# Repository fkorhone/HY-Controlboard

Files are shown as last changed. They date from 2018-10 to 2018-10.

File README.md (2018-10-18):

# HY-Controlboard
General purpose microcontroller board for measurements and prototyping

## Copying
HY controlboard - Generic purpose control board for measurements and control
Copyright (c) 2018 Frans Korhonen

HY controlboard was originally developed at Institute for Atmospheric 
and Earth System Research / Physics, Faculty of Science, 
University of Helsinki, Finland

Assistance, experience, and feedback from following persons have been 
critical in the original work: Erkki Siivola, Lauri Ahonen, 
Juha Kangasluoma, Pasi Aalto, Markku Kulmala and Tuukka Petäjä.

This notice was encoded using utf-8.

This work is licensed under the Creative Commons Attribution-ShareAlike 4.0 International License. 

## Tools used
Drawings have been created using gEDA tools.
http://www.geda-project.org/

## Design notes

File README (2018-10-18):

2014 Frans Korhonen
README for easy geda bats.
Tools for designing printed circuit boards.

Run bats:
cmd.bat - command prompt with geda tools in path variables
X.bat - updates X.pcb from X.sch (Uses bat basename as filename). Follow the instructions on the appearing command window.
gattrib.bat - starts gattrib schematic attribute editor. Handy for setting component footprints and adding supplier references etc.
gerbv.bat - Gerber viewer. View production gerber layers.
gschem.bat - Schematic editor. Adds project related component symbols from "components/" directory.
pcb.bat - Layout editor. finds project related footprints from "packages/" directory. 
bom.bat - create bill of materials from schematics defined inside the bat.

directories:
components/ - project component symbol location.
packages - project fooprint location.
gerber/ - directory for pcb production gerbers.
src/ - firmware source code.
bom/ - Directory for bill of materials

other files:
gafrc - Required for project components seen properly.
round_mm_vendor - Vendor drill mapping file for PCB. mm drills.
attribs - fields that will be seen in bill of materials

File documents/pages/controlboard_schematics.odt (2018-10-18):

# HY-controlboard

Generic purpose control board for measurements and control

Version 2.3 Schematics

## Known issues, date: 2018-10-04:

-Pull down & down resistors need to be added for rs485/422 . (eg. 750ohm)

-R39, R44 removed. Caused unwanted echoing in serial.

-10K pull-up needed for serial1 RTS. Connect between J43 and 12V. (RS485 transmit need to be non-active when serial1 cable disconnected.)

HY controlboard - Generic purpose control board for measurements and control Copyright (c) 2018 Frans Korhonen HY controlboard was originally developed at Institute for Atmospheric and Earth System Research / Physics, Faculty of Science, University of Helsinki, Finland Assistance, experience, and 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

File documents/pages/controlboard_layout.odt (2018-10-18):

# HY-controlboard

Generic purpose control board for measurements and control

Version 2.3 PCB Layout

## Known issues, date: 2018-10-04:

-CONN4 and U15 are in collision. CONN4 needs manual cut to fit.

-CONN13 and R32 are in collision. CONN13 needs manual cut to fit.

-COINCELL too close to connector EXT1 and EXT2.

-COINCELL at front of J37.

-CONN6 holes loose

-CONN20 holes loose

-EXT2 holes loose

-EXT1 holes loose

-CONN17 holes loose

-M1 holes loose

HY controlboard - Generic purpose control board for measurements and control Copyright (c) 2018 Frans Korhonen HY controlboard was originally developed at Institute for Atmospheric and Earth System Research / Physics, Faculty of Science, University of Helsinki, Finland Assistance, experience, and 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

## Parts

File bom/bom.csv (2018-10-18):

refdes | value | footprint | farnell | qty/1 | model-name
J49 | ? | smdjmp | unknown | unknown | unknown
R43 | 120R | RTH300mil | 9342419 | 1 | MF12 10K
J44 | ? | smdjmp | unknown | unknown | unknown
J45 | ? | smdjmp | unknown | unknown | unknown
J46 | ? | smdjmp | unknown | unknown | unknown
CONN17 | unknown | HEADER10_2 | 1593442
 | unknown | 2213S-10G
J37 | ? | smdjmp | unknown | unknown | unknown
D7 | unknown | DTH300mil | unknown | unknown | unknown
R48 | 40K | RTH300mil | 9342419 | 1 | MF12 10K
R47 | 2K | RTH300mil | 9342419 | 1 | MF12 10K
C1 | 100n | CTH200mil | 1215508 | 1 | BFC237011104
C8 | 100n | CTH200mil | 1215508 | 1 | BFC237011104
C7 | 100n | CTH200mil | 1215508 | 1 | BFC237011104
C5 | 100n | CTH200mil | 1215508 | 1 | BFC237011104
C6 | 100n | CTH200mil | 1215508 | 1 | BFC237011104
232_D9M2 | - | D9ML | 1099289 | 1 | 8LCM009P-301B-XX
232_D9M1 | - | D9ML | 1099289 | 1 | 8LCM009P-301B-XX
U1 | - | DIP16 | 9605495 | 1 | ADM202EANZ
J43 | ? | smdjmp | unknown | unknown | unknown
J40 | ? | smdjmp | unknown | unknown | unknown
J41 | ? | smdjmp | unknown | unknown | unknown
J42 | ? | smdjmp | unknown | unknown | unknown
232_D9F1 | unknown | D9FL | 1099294 | 1 | 8LCM009S-304B-XX
R41 | 10k | RTH300mil | 9342419 | 1 | MF12 10K
R39 | 10k | RTH300mil | 9342419 | 1 | MF12 10K
R44 | 10k | RTH300mil | 9342419 | 1 | MF12 10K
CONN19 | - | SIP2 | unknown | 0 | unknown
J39 | - | SIP5 | unknown | unknown | unknown
J38 | - | SIP5 | unknown | unknown | unknown
CONN18 | - | SIP5 | unknown | 0 | unknown
U17 | unknown | DIP14 | 1739924 | 1 | CD74HC08E
J34 | ? | smdjmp | unknown | unknown | unknown
J33 | ? | smdjmp | unknown | unknown | unknown
J36 | ? | smdjmp | unknown | unknown | unknown
J35 | ? | smdjmp | unknown | unknown | unknown
U16 | unknown | DIP14 | 2460682 | 1 | ADM489ANZ
J5 | ? | smdjmp | unknown | unknown | unknown
J4 | ? | smdjmp | unknown | unknown | unknown
J7 | ? | smdjmp | unknown | unknown | unknown
J9 | ? | smdjmp | unknown | unknown | unknown
J2 | ? | smdjmp | unknown | unknown | unknown
J1 | ? | smdjmp | unknown | unknown | unknown
C2 | 100n | CTH200mil | 1215508 | 1 | BFC237011104
C15 | 100n | CTH200mil | 1215508 | 1 | BFC237011104
C23 | 100n | CTH200mil | 1215508 | 1 | BFC237011104
C16 | 100n | CTH200mil | 1215508 | 1 | BFC237011104
C19 | 100n | CTH200mil | 1215508 | 1 | BFC237011104
U2 | - | DIP16 | 9605495 | 1 | ADM202EANZ
CONN20 | unknown | TERM2_100mil | 2007967 | unknown | MC000001
CONN6 | unknown | TERM3_100mil | 2007968 | unknown | MC000002
CONN11 | unknown | TERM8C_100mil | 2007972 | unknown | MC000006
CONN9 | unknown | TERM10C_100mil | 2007973 | unknown | MC000007
CONN12 | - | power2_200mil | 1793049 | 1 | MFKDSP/ 2-5,08
R45 | 1M | RTH300mil | 9342435 | 1 | MF12 1M
M2 | unknown | traco_tmr | 1284245 | unknown | TMR 6-2411WI
F1 | 200mA | RTH300mil | 1861122 | 1 | MC36187
C17 | 330n | CTH200mil | 1215512 | 1 | BFC237011334
C18 | 100n | CTH200mil | 1215508 | 1 | BFC237011104
U4 | 10V | 78XX_TO220 | 2451062 | 1 | LM7810ACT
M3 | TMH0512S | traco_tmh | 1007552 | 1 | TMH0512S
CONN1 | unknown | TERM6C_100mil | 2007971 | unknown | MC000005
CONN3 | unknown | TERM8C_100mil | 2007972 | unknown | MC000006
CONN10 | unknown | TERM8C_100mil | 2007972 | unknown | MC000006
R13 | 34K | RTH300mil | 1083419 | 1 | YR1B34KCC
R12 | 34K | RTH300mil | 1083419 | 1 | YR1B34KCC
R11 | 34K | RTH300mil | 1083419 | 1 | YR1B34KCC
R9 | 34K | RTH300mil | 1083419 | 1 | YR1B34KCC
R8 | 34K | RTH300mil | 1083419 | 1 | YR1B34KCC
R7 | 66K5 | RTH300mil | 1083450 | 1 | YR1B66K5CC
C14 | - | CTH200mil | - | 0 | unknown
C13 | 100n | CTH200mil | 1215508 | 1 | BFC237011104
C12 | 100n | CTH200mil | 1215508 | 1 | BFC237011104
C11 | 100n | CTH200mil | 1215508 | 1 | BFC237011104
C10 | 100n | CTH200mil | 1215508 | 1 | BFC237011104
C9 | 100n | CTH200mil | 1215508 | 1 | BFC237011104
R6 | - | RTH300mil | - | 0 | unknown
R5 | - | RTH300mil | - | 0 | unknown
R4 | 66K5 | RTH300mil | 1083450 | 1 | YR1B66K5CC
R3 | 66K5 | RTH300mil | 1083450 | 1 | YR1B66K5CC
R2 | 66K5 | RTH300mil | 1083450 | 1 | YR1B66K5CC
R1 | 34K | RTH300mil | 1083419 | 1 | YR1B34KCC
R23 | 66K5 | RTH300mil | 1083450 | 1 | YR1B66K5CC
R22 | 66K5 | RTH300mil | 1083450 | 1 | YR1B66K5CC
R19 | 66K5 | RTH300mil | 1083450 | 1 | YR1B66K5CC
R18 | 66K5 | RTH300mil | 1083450 | 1 | YR1B66K5CC
R17 | 66K5 | RTH300mil | 1083450 | 1 | YR1B66K5CC
R16 | ? | RTH300mil | unknown | 0 | unknown
R15 | ? | RTH300mil | unknown | 0 | unknown
R14 | ? | RTH300mil | unknown | 0 | unknown
R31 | 66K5 | RTH300mil | 1083450 | 1 | YR1B66K5CC
R30 | 66K5 | RTH300mil | 1083450 | 1 | YR1B66K5CC
R29 | 34K | RTH300mil | 1083419 | 1 | YR1B34KCC
R28 | 34K | RTH300mil | 1083419 | 1 | YR1B34KCC
R27 | 34K | RTH300mil | 1083419 | 1 | YR1B34KCC
R26 | 34K | RTH300mil | 1083419 | 1 | YR1B34KCC
R25 | 34K | RTH300mil | 1083419 | 1 | YR1B34KCC
R24 | 34K | RTH300mil | 1083419 | 1 | YR1B34KCC
C20 | 100n | CTH200mil | 1215508 | 1 | BFC237011104
C28 | 100n | CTH200mil | 1215508 | 1 | BFC237011104
C27 | 100n | CTH200mil | 1215508 | 1 | BFC237011104
C26 | 100n | CTH200mil | 1215508 | 1 | BFC237011104
C25 | 100n | CTH200mil | 1215508 | 1 | BFC237011104
C24 | 100n | CTH200mil | 1215508 | 1 | BFC237011104
C22 | 100n | CTH200mil | 1215508 | 1 | BFC237011104
C21 | 100n | CTH200mil | 1215508 | 1 | BFC237011104
U5 | mux | DIP16 | 2334931 | 0 | CD4051BM96
CONN16 | unknown | TERM4_100mil | 2007969 | unknown | MC000003
CONN14 | unknown | TERM4_100mil | 2007969 | unknown | MC000003
CONN15 | unknown | TERM4C_100mil | 2007969 | unknown | MC000003
J31 | ? | smdjmp | unknown | unknown | unknown
J32 | ? | smdjmp | unknown | unknown | unknown
R42 | 330R | RTH300mil | 9343032 | 1 | MF12 330R
U15 | unknown | DIP8 | 2083108 | 1 | FOD3182
J29 | ? | smdjmp | unknown | unknown | unknown
J30 | ? | smdjmp | unknown | unknown | unknown
R40 | 330R | RTH300mil | 9343032 | 1 | MF12 330R
U14 | unknown | DIP8 | 2083108 | 1 | FOD3182
J27 | ? | smdjmp | unknown | unknown | unknown
J28 | ? | smdjmp | unknown | unknown | unknown
R38 | 330R | RTH300mil | 9343032 | 1 | MF12 330R
U13 | unknown | DIP8 | 2083108 | 1 | FOD3182
J25 | ? | smdjmp | unknown | unknown | unknown
J26 | ? | smdjmp | unknown | unknown | unknown
R37 | 330R | RTH300mil | 9343032 | 1 | MF12 330R
U12 | unknown | DIP8 | 2083108 | unknown | FOD3182
CONN13 | unknown | TERM5_100mil | 2007970 | unknown | MC000004
CONN4 | unknown | TERM5_100mil | 2007970 | unknown | MC000004
CONN5 | unknown | TERM5C_100mil | 2007970 | unknown | MC000004
D5 | unknown | DTH300mil | 2723902 | 1 | 1N4003G
J24 | ? | smdjmp | unknown | unknown | unknown
J22 | ? | smdjmp | unknown | unknown | unknown
R36 | 330R | RTH300mil | 9343032 | 1 | MF12 330R
U11 | unknown | DIP6 | 1708441 | unknown | ASSR-1611-001E
D4 | unknown | DTH300mil | 2723902 | 1 | 1N4003G
J23 | ? | smdjmp | unknown | unknown | unknown
J20 | ? | smdjmp | unknown | unknown | unknown
R35 | 330R | RTH300mil | 9343032 | 1 | MF12 330R
U10 | unknown | DIP6 | 1708441 | unknown | ASSR-1611-001E
D3 | unknown | DTH300mil | 2723902 | 1 | 1N4003G
J21 | ? | smdjmp | unknown | unknown | unknown
J18 | ? | smdjmp | unknown | unknown | unknown
R34 | 330R | RTH300mil | 9343032 | 1 | MF12 330R
U9 | unknown | DIP6 | 1708441 | unknown | ASSR-1611-001E
D2 | unknown | DTH300mil | 2723902 | 1 | 1N4003G
J19 | ? | smdjmp | unknown | unknown | unknown
J13 | ? | smdjmp | unknown | unknown | unknown
R33 | 330R | RTH300mil | 9343032 | 1 | MF12 330R
U8 | unknown | DIP6 | 1708441 | unknown | ASSR-1611-001E
D1 | unknown | DTH300mil | 2723902 | 1 | 1N4003G
J14 | ? | smdjmp | unknown | unknown | unknown
J3 | ? | smdjmp | unknown | unknown | unknown
R32 | 330R | RTH300mil | 9343032 | 1 | MF12 330R
U7 | unknown | DIP6 | 1708441 | unknown | ASSR-1611-001E
R46 | 10K | RTH300mil | - | 0 | unknown
R49 | 10K | RTH300mil | - | 0 | unknown
EXT2 | unknown | HEADER10_2 | 1593442
 | 1 | 2213S-10G
EXT1 | unknown | HEADER26_2 | 1622415 | 1 | 77313-118-26LF
U18 | unknown | DIP14 | 1739569 | unknown | CD74HC125E
COUNTER1 | unknown | TERM3_100mil | 2007968 | unknown | MC000002
CONN7 | unknown | TERM6C_100mil | 2007971 | unknown | MC000005
U6 | unknown | DIP16 | 9591664 | unknown | SN74HC595N
J17 | ? | smdjmp | unknown | unknown | unknown
J16 | ? | smdjmp | unknown | unknown | unknown
J15 | ? | smdjmp | unknown | unknown | unknown
J12 | ? | smdjmp | unknown | unknown | unknown
J11 | ? | smdjmp | unknown | unknown | unknown
J10 | ? | smdjmp | unknown | unknown | unknown
J8 | ? | smdjmp | unknown | unknown | unknown
J6 | ? | smdjmp | unknown | unknown | unknown
COINCELL | 20mm | coincell | 2064715 | 1 | CH25-2032LF
R21 | 15K | RTH200mil | 9341331 | 1 | MF25 15K
R20 | 15K | RTH200mil | 9341331 | 1 | MF25 15K
USBDEVICE1 | - | USB_B | 1696537 | 1 | MC32596
USBHOST1 | - | USB_A | 1696534 | 0 | unknown
CONN8 | - | magjack | 1901301 | 1 | 0813-1X1T-57-F
R10 | - | RTH300mil | - | 0 | unknown
SD_SPI1 | SDAMB-01215BT00 | SD_SMD | 9186140 | 1 | SDAMB-01215BT00
CONN2 | - | TERM6_100mil | 2007971 | 1 | MC000005
M1 | unknown | MBED | 1761179 | 1 | mbed_lpc1768

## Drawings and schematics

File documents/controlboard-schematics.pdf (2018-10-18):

# HY-controlboard

## Generic purpose control board for measurements and control

## Version 2.3 Schematics

## Known issues, date: 2018-10-04:

-Pull down & down resistors need to be added for rs485/422 . (eg. 750ohm)

-R39, R44 removed. Caused unwanted echoing in serial.

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

### HY controlboard - Generic purpose control board for measurements and control Copyright (c) 2018 Frans Korhonen

HY controlboard was originally developed at Institute for Atmospheric and Earth System Research / Physics,

### Faculty of Science, University of Helsinki, Finland

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

This work is licensed under the Creative Commons Attribution-ShareAlike 4.0 International License.

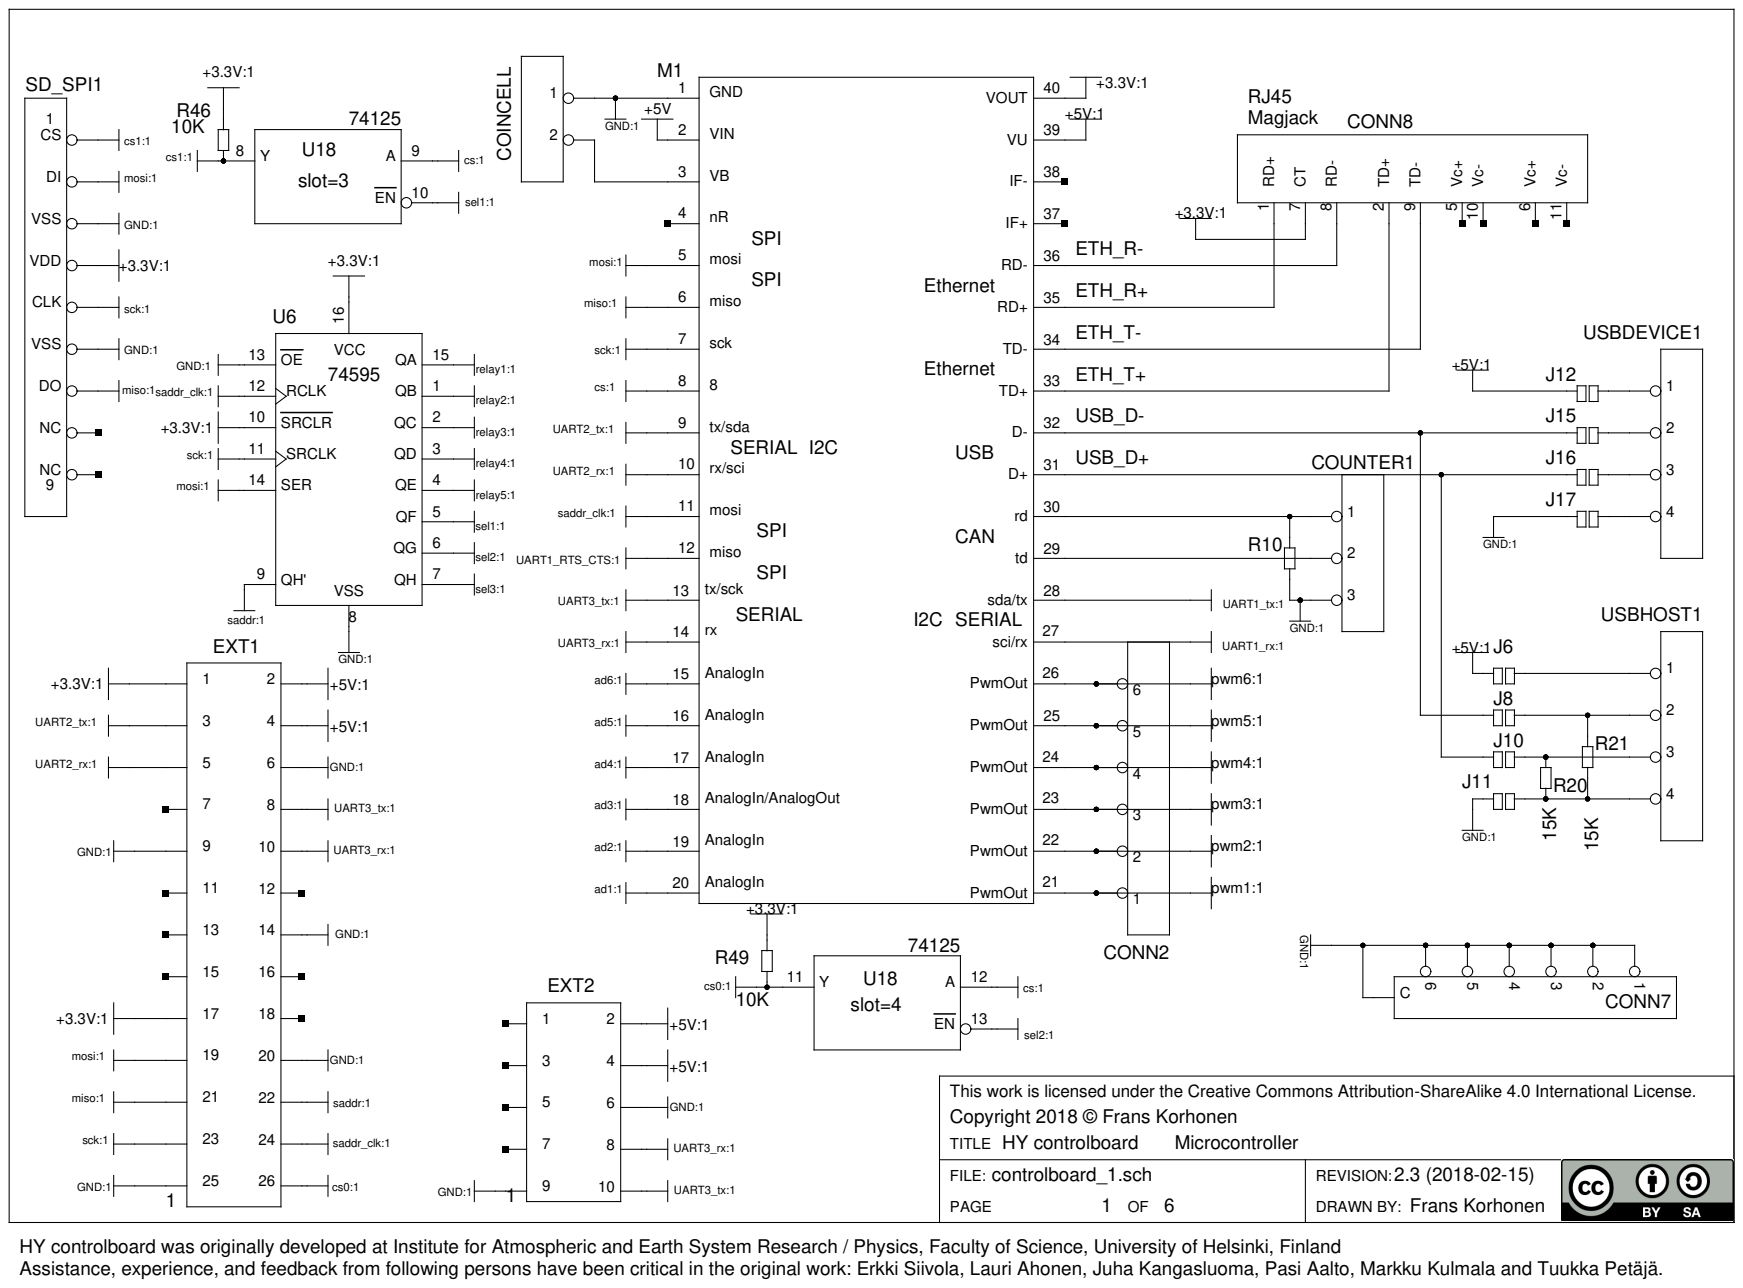
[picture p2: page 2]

27 sci/rx

26 PwmOut
25 PwmOut | 6

24 PwmOut | 5

23 PwmOut | 4

22 PwmOut | 3

This work is licensed under the Creative Commons Attribution-ShareAlike 4.0 International License.
Copyright 2018 © Frans Korhonen
HY controlboard
controlboard_1.sch

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

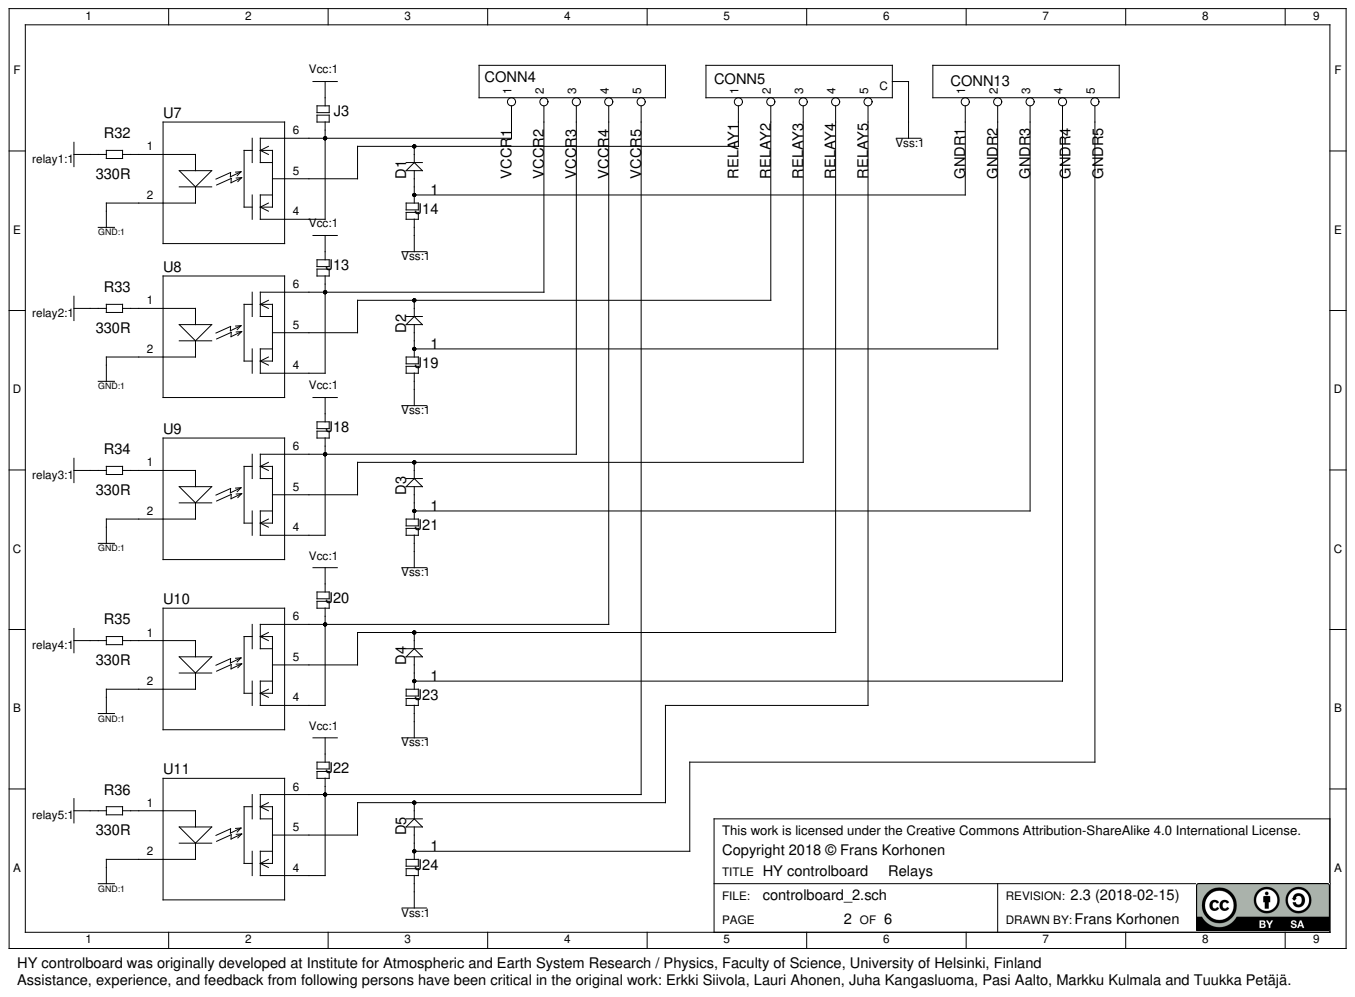
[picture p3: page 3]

This work is licensed under the Creative Commons Attribution-ShareAlike 4.0 International License.
Copyright 2018 © Frans Korhonen
HY controlboard
controlboard_2.sch

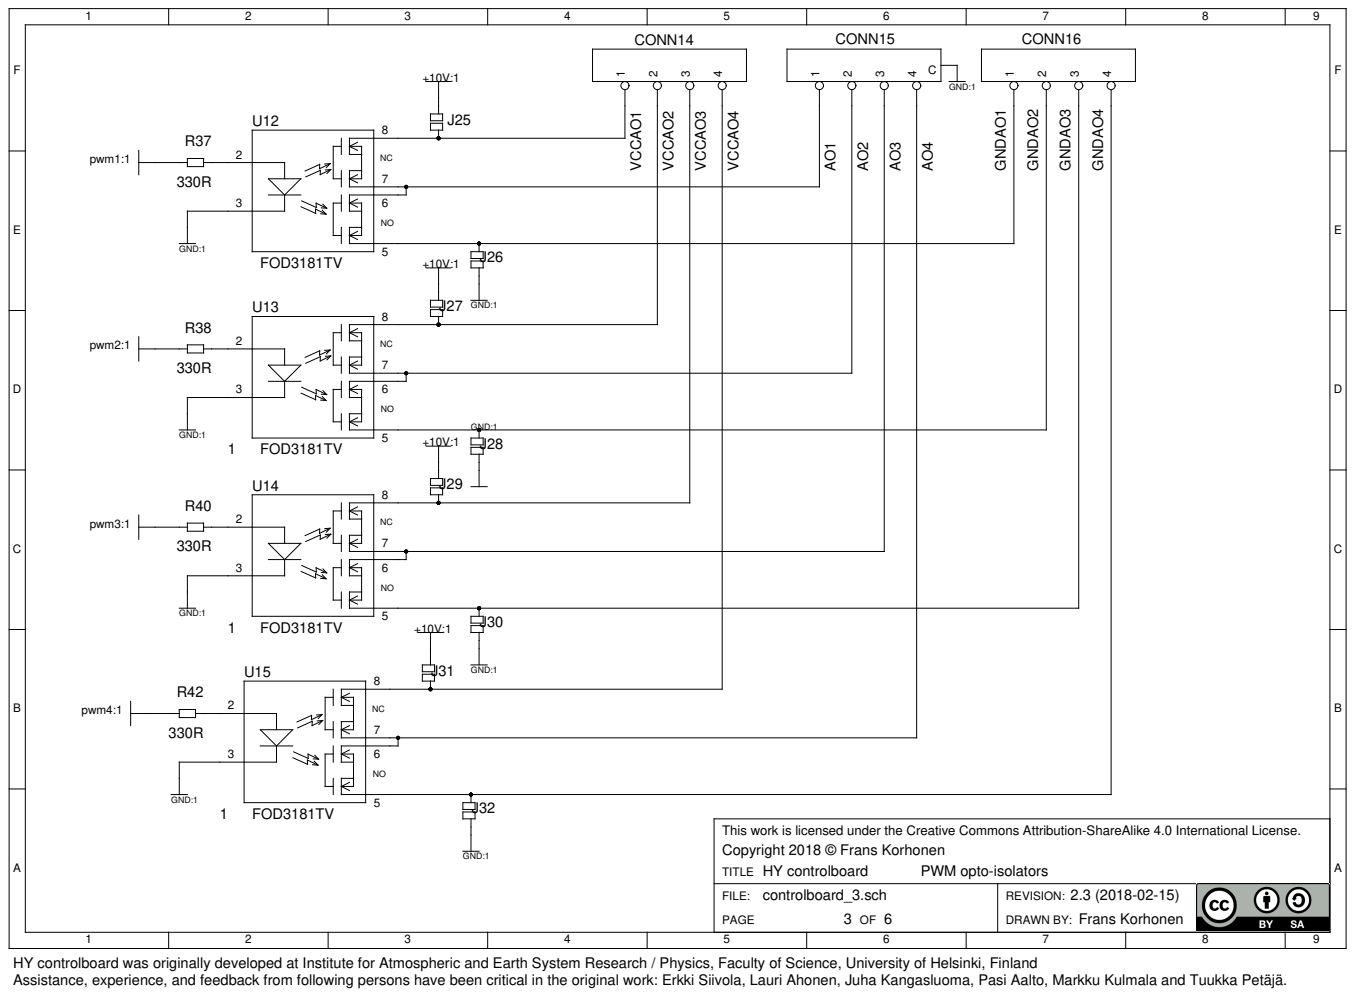
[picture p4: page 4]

This work is licensed under the Creative Commons Attribution-ShareAlike 4.0 International License.
Copyright 2018 © Frans Korhonen
HY controlboard
controlboard_3.sch

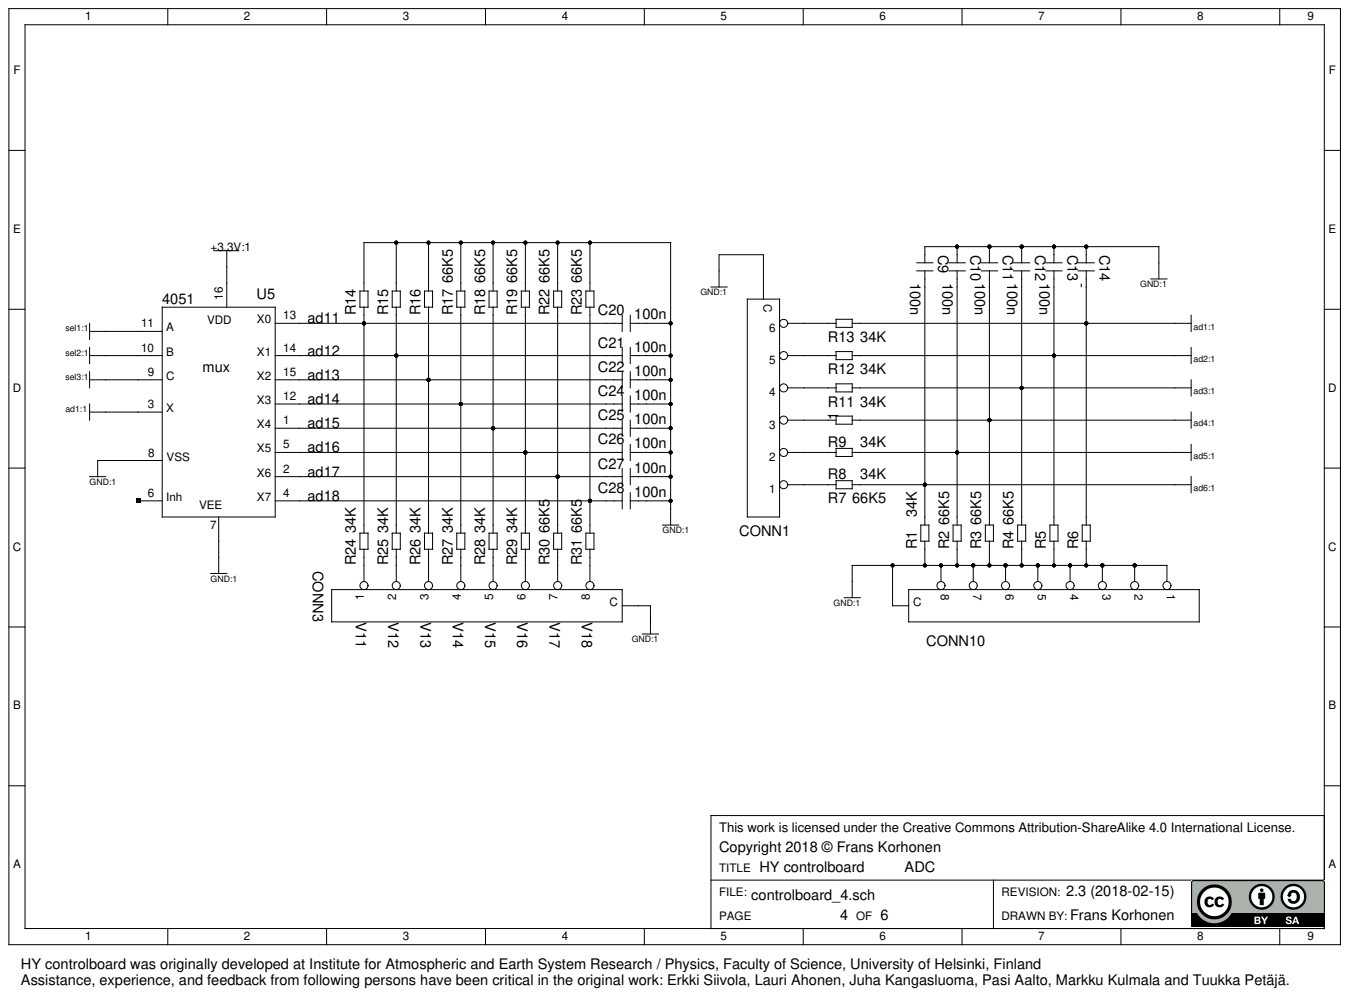
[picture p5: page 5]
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

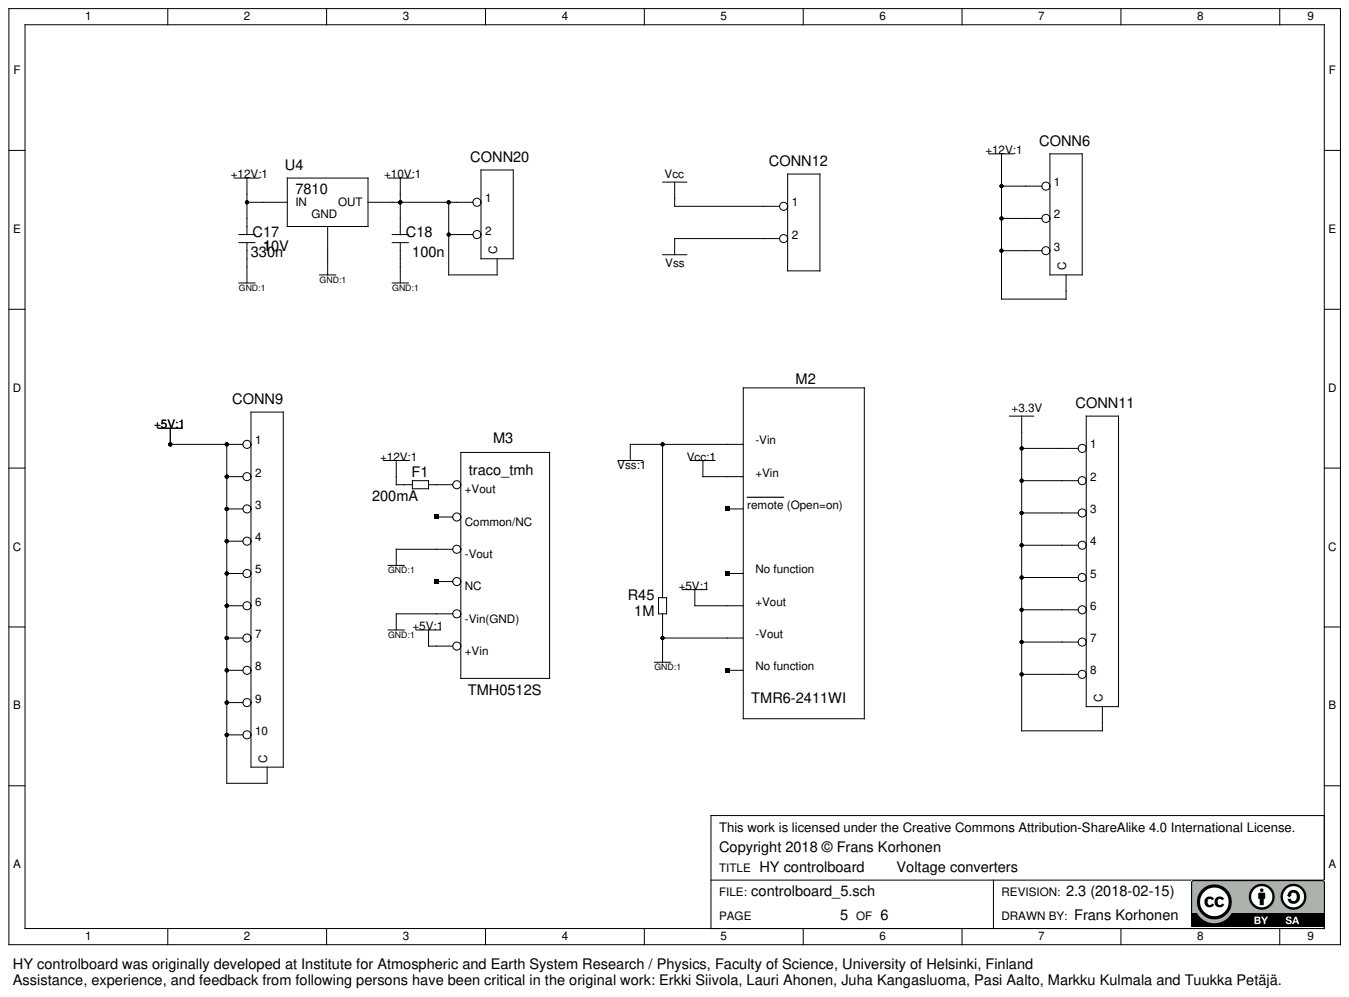
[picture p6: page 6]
FILE:; REVISION:; PAGE; DRAWN BY:; A TITLE; +Vin; -Vin(GND); -Vout; Common/NC; +Vout; traco_tmh; TMH0512S; GND:1; GND; OUT; Vcc:1 Vss:1; -Vin; No function; TMR6-2411WI; CONN12; Vcc; Vss; CONN9; CONN11; CONN6; Frans Korhonen; Voltage converters; CONN20

remote (Open=on)

This work is licensed under the Creative Commons Attribution-ShareAlike 4.0 International License.
Copyright 2018 © Frans Korhonen
HY controlboard
controlboard_5.sch

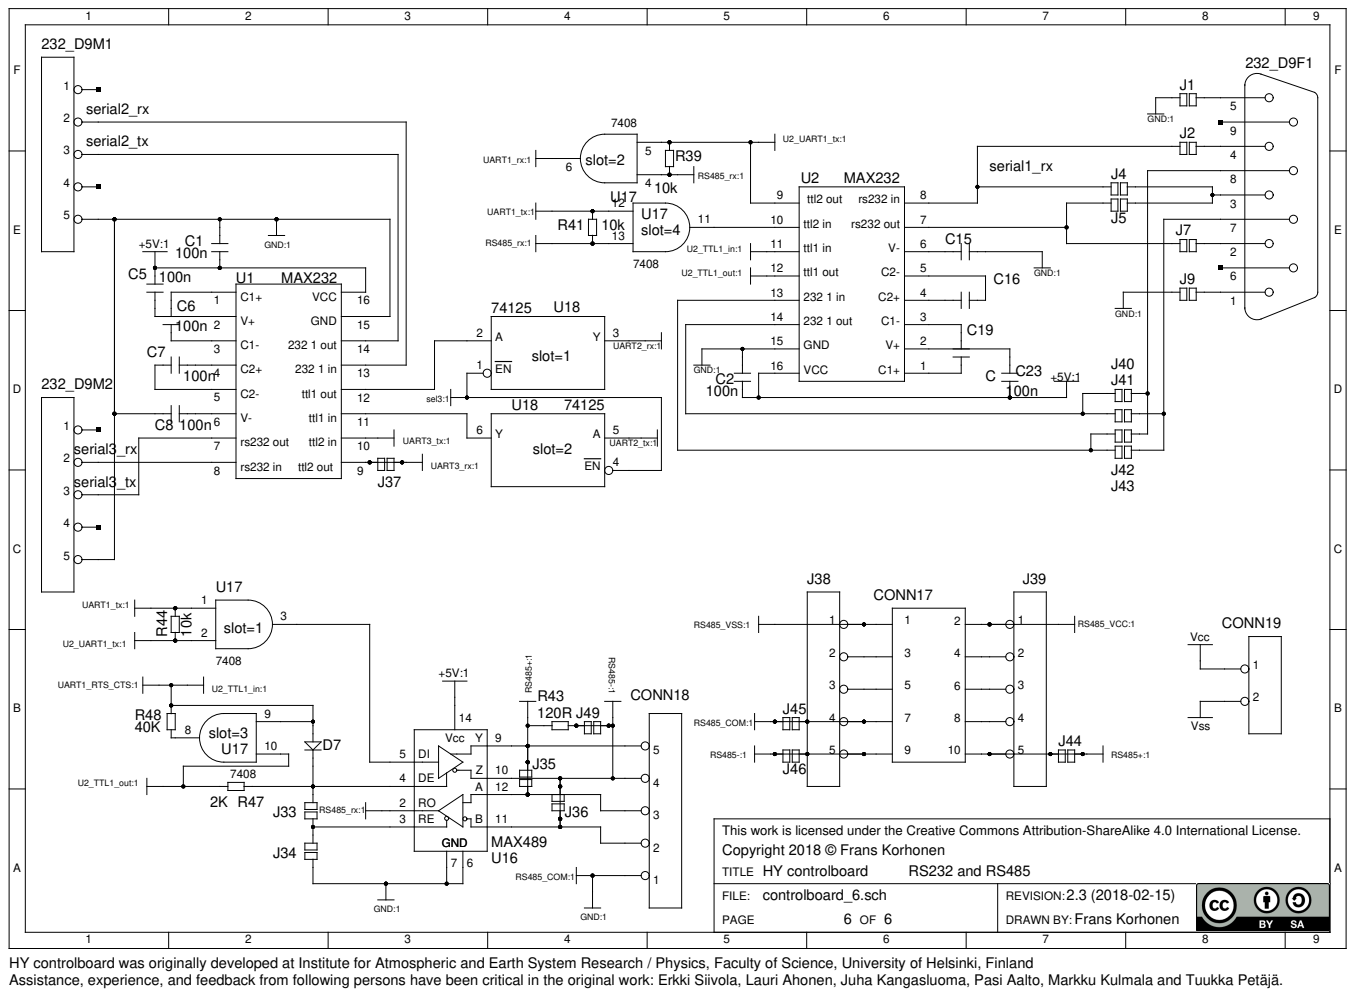
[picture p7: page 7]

This work is licensed under the Creative Commons Attribution-ShareAlike 4.0 International License.
Copyright 2018 © Frans Korhonen
HY controlboard
controlboard_6.sch

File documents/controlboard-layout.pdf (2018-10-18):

# HY-controlboard

Generic purpose control board for measurements and control

Version 2.3 PCB Layout

Known issues, date: 2018-10-04:

-CONN4 and U15 are in collision. CONN4 needs manual cut to fit.

-CONN13 and R32 are in collision. CONN13 needs manual cut to fit.

-COINCELL too close to connector EXT1 and EXT2.

-COINCELL at front of J37.

-CONN6 holes loose

-CONN20 holes loose

-EXT2 holes loose

-EXT1 holes loose

-CONN17 holes loose

-M1 holes loose

HY controlboard - Generic purpose control board for measurements and control
Copyright (c) 2018 Frans Korhonen

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

This work is licensed under the Creative Commons Attribution-ShareAlike 4.0 International License.

# /home/frans/Documents/controlboard.pcb

# 1. Table of Contents (This Page) Created on Thu Oct 4 21:02:50 2018

# 2. component 3. solder 4. outline 5. plated-drill 6. componentmask 7. soldermask 8. topsilk 9. bottomsilk 10. toppaste 11. bottompaste 12. topassembly 13. bottomassembly 14. fab

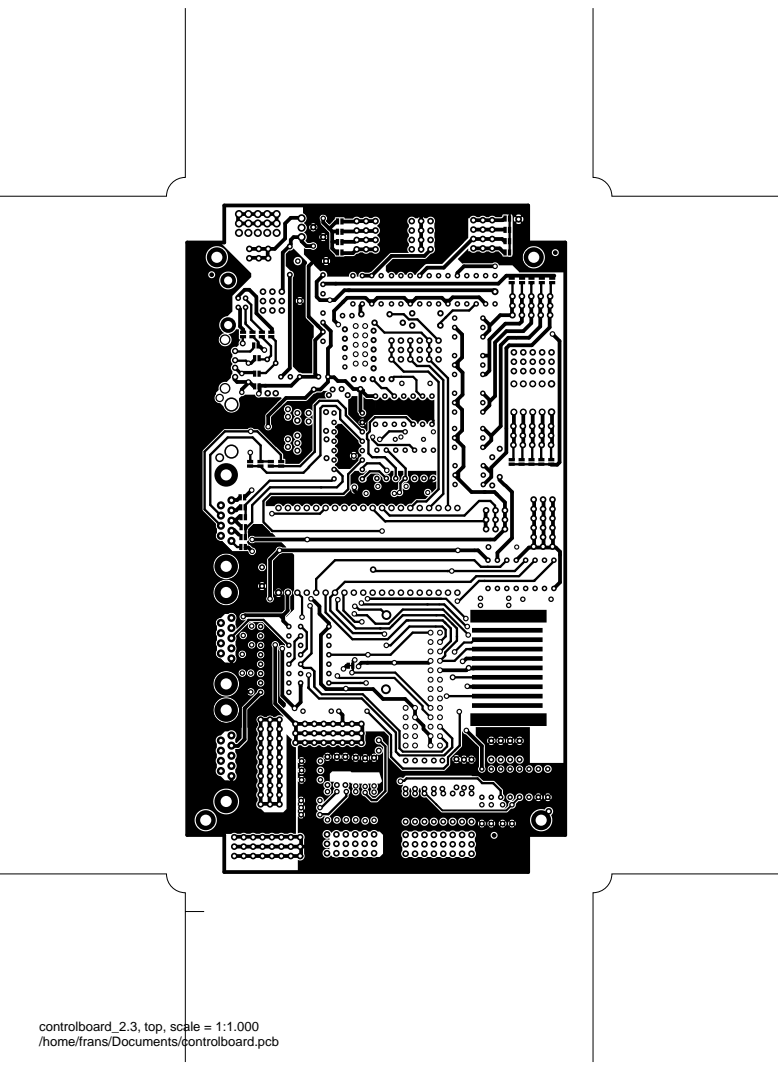
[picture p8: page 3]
controlboard_2.3, top, scale = 1:1.000

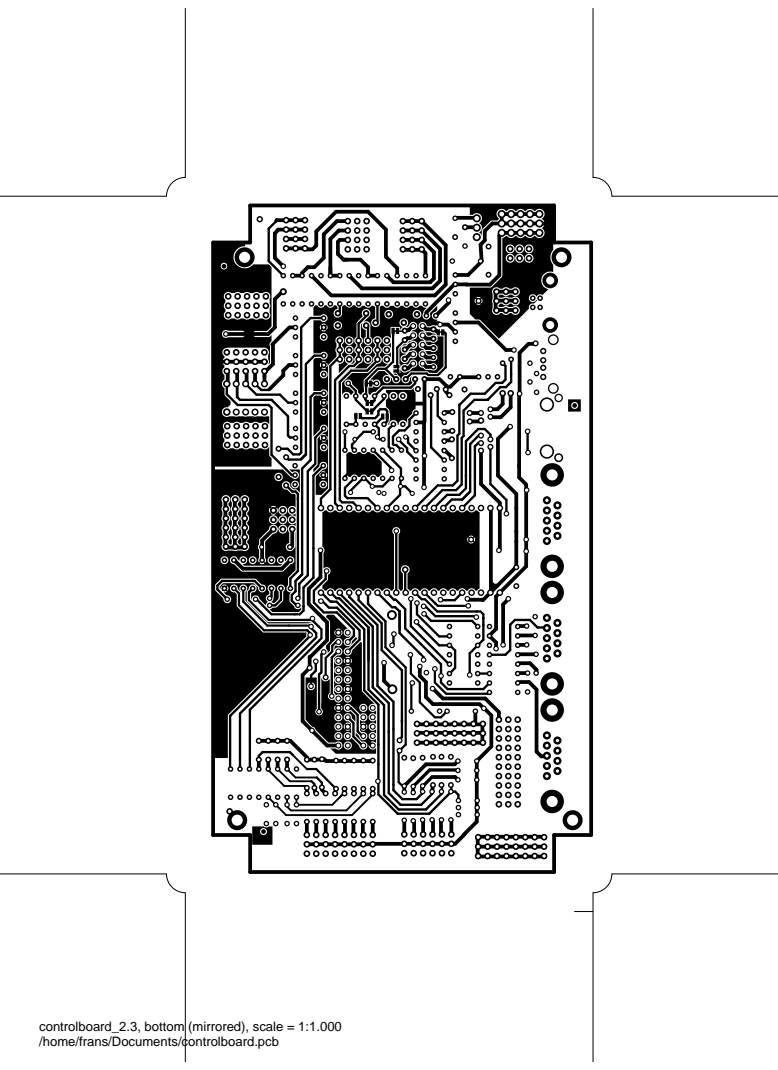
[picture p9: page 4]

controlboard_2.3, bottom (mirrored), scale = 1:1.000

controlboard_2.3, outline, scale = 1:1.000

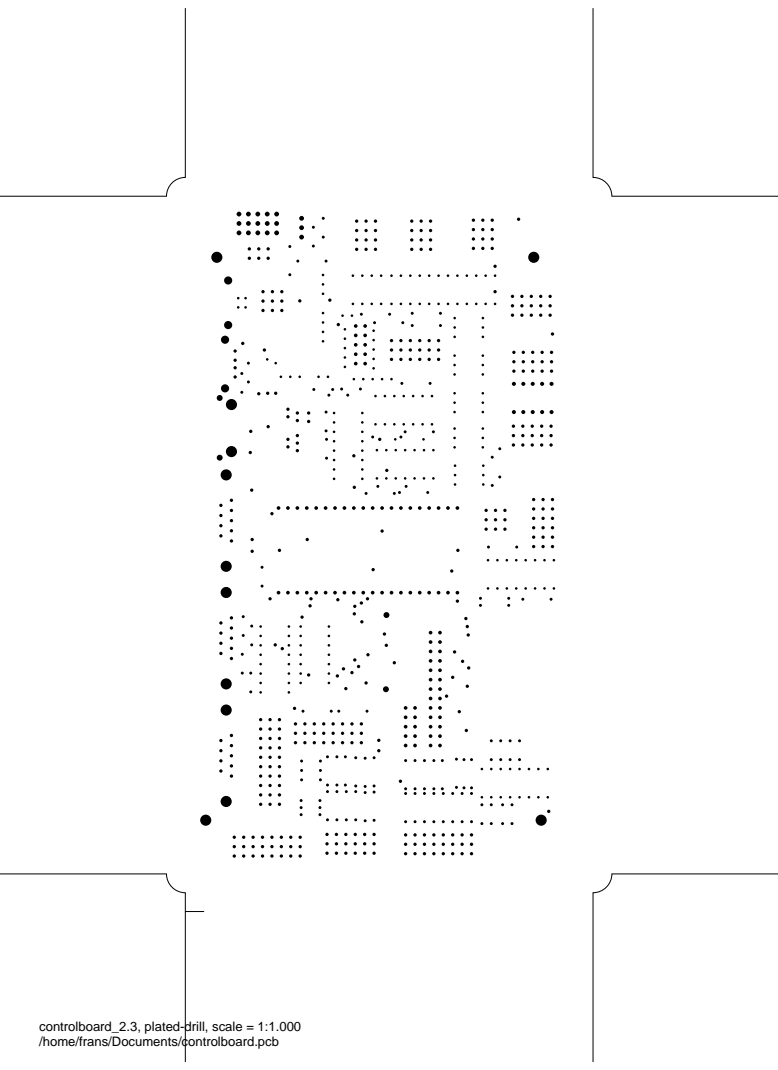
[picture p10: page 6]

controlboard_2.3, plated-drill, scale = 1:1.000

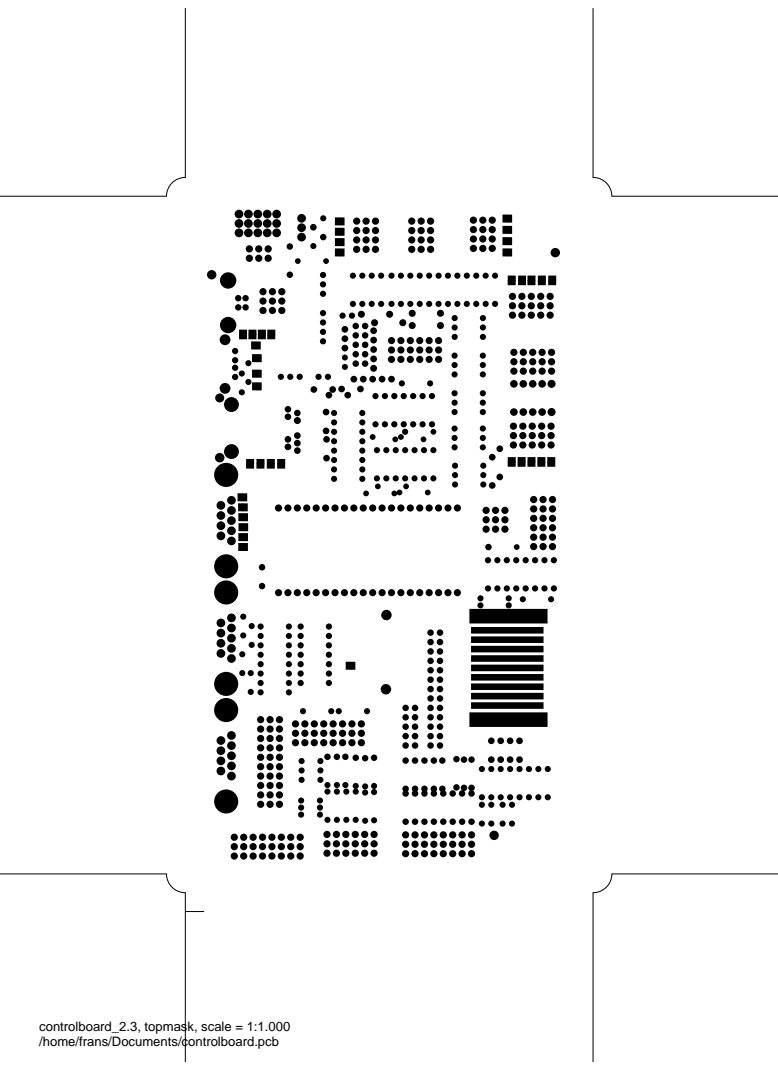
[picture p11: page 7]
controlboard_2.3, topmask, scale = 1:1.000

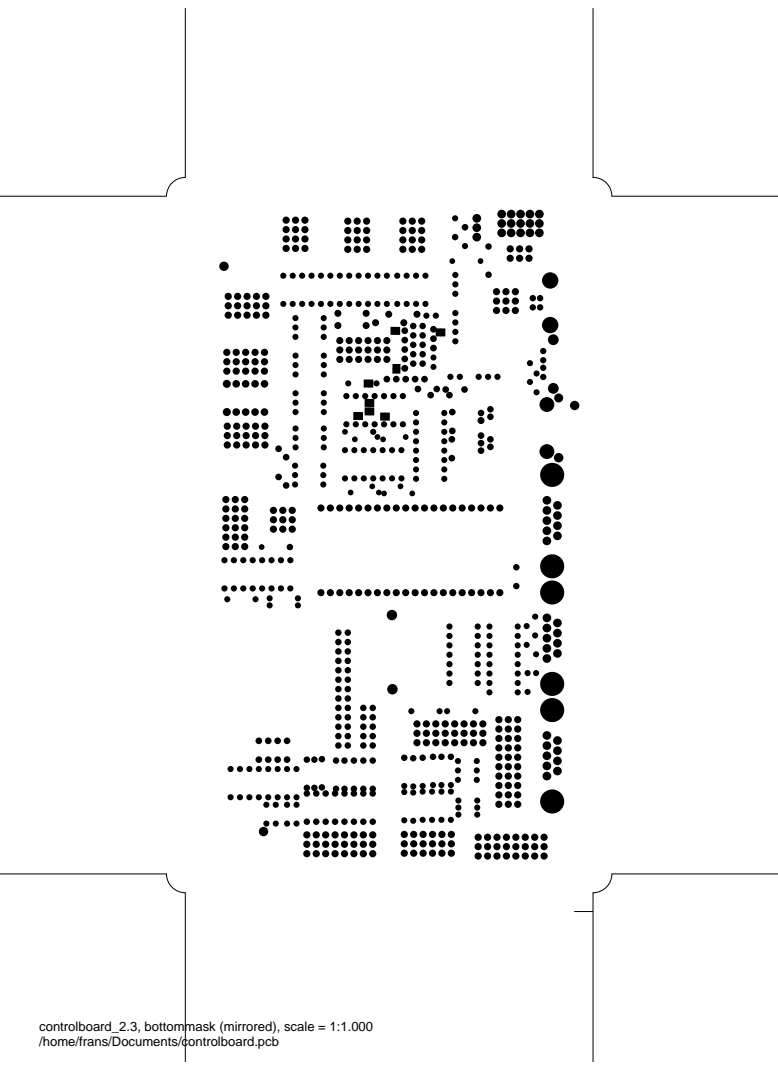
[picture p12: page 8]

controlboard_2.3, bottommask (mirrored), scale = 1:1.000

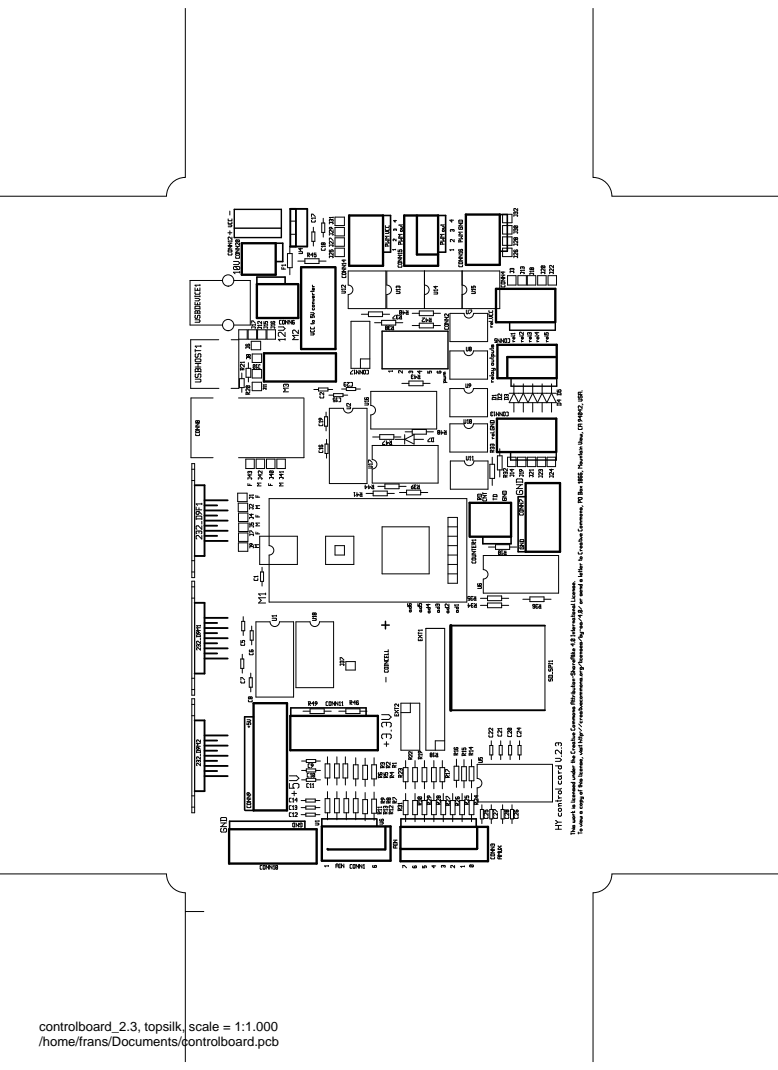
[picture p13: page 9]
controlboard_2.3, topsilk, scale = 1:1.000

controlboard_2.3, bottomsilk (mirrored), scale = 1:1.000 controlboard_2.3, toppaste, scale = 1:1.000 controlboard_2.3, bottompaste (mirrored), scale = 1:1.000

controlboard_2.3, topassembly, scale = 1:1.000


controlboard_2.3, bottomassembly (mirrored), scale = 1:1.000

controlboard_2.3, fab, scale = 1:1.000

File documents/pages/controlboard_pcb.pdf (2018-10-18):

# /home/frans/Documents/controlboard.pcb

# 1. Table of Contents (This Page) Created on Thu Oct 4 21:02:50 2018

# 2. component 3. solder 4. outline 5. plated-drill 6. componentmask 7. soldermask 8. topsilk 9. bottomsilk 10. toppaste 11. bottompaste 12. topassembly 13. bottomassembly 14. fab

controlboard_2.3, top, scale = 1:1.000


controlboard_2.3, bottom (mirrored), scale = 1:1.000

controlboard_2.3, outline, scale = 1:1.000


controlboard_2.3, plated-drill, scale = 1:1.000

controlboard_2.3, topmask, scale = 1:1.000


controlboard_2.3, bottommask (mirrored), scale = 1:1.000

controlboard_2.3, topsilk, scale = 1:1.000

controlboard_2.3, bottomsilk (mirrored), scale = 1:1.000 controlboard_2.3, toppaste, scale = 1:1.000 controlboard_2.3, bottompaste (mirrored), scale = 1:1.000

controlboard_2.3, topassembly, scale = 1:1.000


controlboard_2.3, bottomassembly (mirrored), scale = 1:1.000

controlboard_2.3, fab, scale = 1:1.000
